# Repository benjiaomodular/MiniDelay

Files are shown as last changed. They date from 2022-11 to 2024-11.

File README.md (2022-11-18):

# MiniDelay

A three-knob delay module based on Rene Schmitz' PT2399 delay design. It’s a simple setup with input and output sections designed to work with Eurorack modular synthesizer levels (10Vpp).

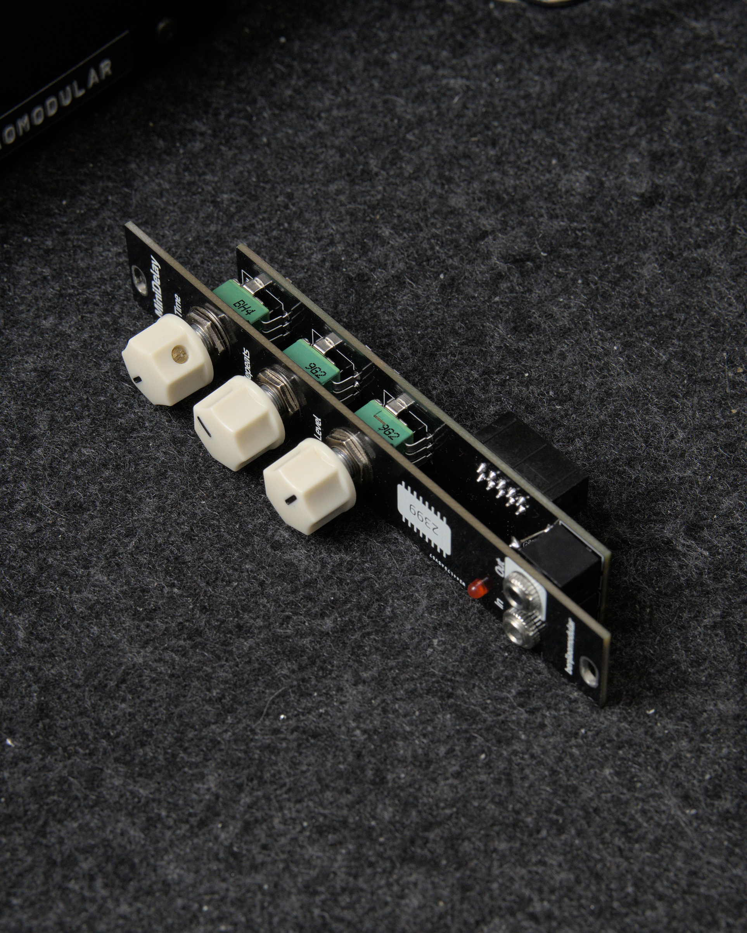
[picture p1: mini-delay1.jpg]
MiniDelay


# More info
For more information about this project, check out my website: https://benjiaomodular.com/post/2022-09-11-mini-delay/

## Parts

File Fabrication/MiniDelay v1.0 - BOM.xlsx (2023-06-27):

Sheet: MiniDelay
Part No. | Reference | Quantity | Value | Manufacturers Name | Manufacturers Part Number | Mfg # | Part Description | Type | LCSC Part # | Package
1 | AudioIn1 AudioOut1 | 2 | AudioJack2_SwitchT | Tayda Electronics | PJ-3001F | PJ-3001F | PJ-3001F 3.5mm Mono Phone Jack | Thru-hole | - | -
2 | C1 C2 | 2 | 22uF | Murata Electronics | GRM21BR61E226ME44L | GRM21BR61E226ME44L | Multilayer Ceramic Capacitors MLCC - SMD/SMT 22UF 25V 20% 0805 | Surface mount | C49678 | 805
3 | C10 C12 C15 C19 | 4 | 2.2nF | YAGEO | CC0603JRNPO9BN222 | CC0603JRNPO9BN222 | Multilayer Ceramic Capacitors MLCC - SMD/SMT 50V 2200pF C0G 0603 5% | Surface mount | C107043 | 603
4 | C14 | 1 | 330nF | YAGEO | CC0603KRX7R8BB334 | CC0603KRX7R8BB334 | Multilayer Ceramic Capacitors MLCC - SMD/SMT 25V 0.33uF X7R 0603 10% | Surface mount | C107070 | 603
5 | C16 | 1 | 15nF | YAGEO | AC0603KRX7R0BB153 | AC0603KRX7R0BB153 | Multilayer Ceramic Capacitors MLCC - SMD/SMT 100 V 0.015 uF X7R 0603 10% AEC-Q200 | Surface mount | C2210963 | 603
6 | C20 | 1 | 4.7nF | YAGEO | CC0603JRX7R9BB472 | CC0603JRX7R9BB472 | Multilayer Ceramic Capacitors MLCC - SMD/SMT 50V 4700pF X7R 0603 5% | Surface mount | C115060 | 603
7 | C21 | 1 | 10nF | YAGEO | CC0603JRX7R9BB103 | CC0603JRX7R9BB103 | Multilayer Ceramic Capacitors MLCC - SMD/SMT 50V 0.01uF X7R 0603 5% | Surface mount | C115056 | 603
8 | C22 | 1 | 68pF | YAGEO | CC0603GRNPO9BN680 | CC0603GRNPO9BN680 | Multilayer Ceramic Capacitors MLCC - SMD/SMT 50 V 68 pF C0G 0603 2% | Surface mount | C519457 | 603
9 | C3 C4 C8 C9 C11 C13 C17 | 7 | 100nF | YAGEO | CC0603JRX7R9BB104 | CC0603JRX7R9BB104 | Multilayer Ceramic Capacitors MLCC - SMD/SMT 50 V 0.1uF X7R 0603 5% | Surface mount | C91183 | 603
10 | C5 | 1 | 220nF | Murata Electronics | GCM188R71H224KA64D | GCM188R71H224KA64D | Multilayer Ceramic Capacitors MLCC - SMD/SMT .22UF 50V 10% 0603 | Surface mount | C97857 | 603
11 | C6 | 1 | 47pF | YAGEO | CC0603JRNPO9BN470 | CC0603JRNPO9BN470 | Multilayer Ceramic Capacitors MLCC - SMD/SMT 50 V 47 pF C0G 0603 5% | Surface mount | C105622 | 603
12 | C7 C18 | 2 | 1uF | Taiyo Yuden | UMK107AB7105KA-T | UMK107AB7105KA-T | Multilayer Ceramic Capacitors MLCC - SMD/SMT 0603 50VDC 1uF 10% X7R | Surface mount | C105174 | 603
13 | D1 | 1 | 3mm_LED | EKINGLUX | EL304RD | EL304RD | 3.0mm Round Through Hole LED | Thru-hole | C2856645 | -
14 | J1 | 1 | IDC_2x05 | XKB Connectivity | X9555WV-2X05-6TV01 | X9555WV-2X05-6TV01 | IDC Connector 2x05 2.54mm Pitch Straight | Thru-hole | C706914 | -
15 | LEVEL1 REPEATS1 | 2 | B10k | Alpha (Taiwan) | RD901F-40-15R1-B10K | RD901F-40-15R1-B10K | 10K OHM Linear Taper Potentiometer Round Shaft PCB 9mm | Thru-hole | - | RD901F
16 | R1 R16 | 2 | 1M | YAGEO | RC0603FR-071ML | RC0603FR-071ML | Thick Film Resistors - SMD 1 MOhms 100mW 0603 1% | Surface mount | C105578 | 603
17 | R18 | 1 | 68k | YAGEO | RC0603FR-0768KL | RC0603FR-0768KL | Thick Film Resistors - SMD 68 kOhms 100mW 0603 1% | Surface mount | C114633 | 603
18 | R2 R4 R8 R10 R11 R12 R13 R14 R15 | 9 | 10k | YAGEO | AC0603FR-0710KL | AC0603FR-0710KL | Thick Film Resistors - SMD 10 kOhms 100mW 0603 1% AEC-Q200 | Surface mount | C116677 | 603
19 | R3 R6 R17 R20 R21 | 5 | 100k | YAGEO | RC0603FR-07100KL | RC0603FR-07100KL | Thick Film Resistors - SMD 100 kOhms 100mW 0603 1% | Surface mount | C14675 | 603
20 | R5 | 1 | 2.7k | YAGEO | RC0603FR-072K7L | RC0603FR-072K7L | Thick Film Resistors - SMD 2.7 kOhms 100mW 0603 1% | Surface mount | C114612 | 603
21 | R7 R19 | 2 | 20k | YAGEO | RC0603FR-0720KL | RC0603FR-0720KL | Thick Film Resistors - SMD 20 kOhms 100mW 0603 1% | Surface mount | C105575 | 603
22 | R9 | 1 | 1k | YAGEO | RC0603FR-071KL | RC0603FR-071KL | Thick Film Resistors - SMD 1 kOhms 100mW 0603 1% | Surface mount | C22548 | 603
23 | TIME1 | 1 | B100k | Alpha (Taiwan) | RD901F-40-15R1-B100K | RD901F-40-15R1-B100K | 100K OHM Linear Taper Potentiometer Round Shaft PCB 9mm | Thru-hole | - | RD901F
24 | U1 | 1 | TL074 | STMicroelectronics | TL074IDT | TL074IDT | Operational Amplifiers - Op Amps Quad Low Noise JFET | Surface mount | C107644 | SOIC-14_150mil
25 | U2 | 1 | PT2399 | PTC(Princeton Tech) | PT2399-SN | PT2399-SN | SOP-16_150mil Audio Interface ICs ROHS | Surface mount | C126407 | SOP-16_150mil
26 | U3 | 1 | L7805 | STMicroelectronics | L7805CDT-TR | L7805CDT-TR | 62dB@(120Hz) 1.5A 2V@(1A) Fixed 5V~5V Positive 1 35V TO-252-3 Linear Voltage Regulators (LDO) ROHS | Surface mount | C310413 | TO-252-3
 |  | 53

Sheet: Sheet2
Part No. | Reference | Quantity | Value | Manufacturers Name | Manufacturers Part Number | Mfg # | Part Description | Type | LCSC Part # | Package
2 | C1 C2 | 2 | 22uF | YAGEO | CC0805KRX7R9BB104 | CC0805KRX7R9BB104 | Multilayer Ceramic Capacitors MLCC - SMD/SMT 50 V 0.1uF X7R 0805 10% | Surface mount | C49678 | 805
3 | C10 C12 C15 C19 | 4 | 2.2nF | YAGEO | CC0603JRNPO9BN222 | CC0603JRNPO9BN222 | Multilayer Ceramic Capacitors MLCC - SMD/SMT 50V 2200pF C0G 0603 5% | Surface mount | C107043 | 603
4 | C14 | 1 | 330nF | YAGEO | CC0603KRX7R8BB334 | CC0603KRX7R8BB334 | Multilayer Ceramic Capacitors MLCC - SMD/SMT 25V 0.33uF X7R 0603 10% | Surface mount | C107070 | 603
5 | C16 | 1 | 15nF | YAGEO | AC0603KRX7R0BB153 | AC0603KRX7R0BB153 | Multilayer Ceramic Capacitors MLCC - SMD/SMT 100 V 0.015 uF X7R 0603 10% AEC-Q200 | Surface mount | C2210963 | 603
6 | C20 | 1 | 4.7nF | YAGEO | CC0603JRX7R9BB472 | CC0603JRX7R9BB472 | Multilayer Ceramic Capacitors MLCC - SMD/SMT 50V 4700pF X7R 0603 5% | Surface mount | C115060 | 603
7 | C21 | 1 | 10nF | YAGEO | CC0603JRX7R9BB103 | CC0603JRX7R9BB103 | Multilayer Ceramic Capacitors MLCC - SMD/SMT 50V 0.01uF X7R 0603 5% | Surface mount | C115056 | 603
8 | C22 | 1 | 68pF | YAGEO | CC0603GRNPO9BN680 | CC0603GRNPO9BN680 | Multilayer Ceramic Capacitors MLCC - SMD/SMT 50 V 68 pF C0G 0603 2% | Surface mount | C519457 | 603
9 | C3 C4 C8 C9 C11 C13 C17 | 7 | 100nF | YAGEO | CC0603JRX7R9BB104 | CC0603JRX7R9BB104 | Multilayer Ceramic Capacitors MLCC - SMD/SMT 50 V 0.1uF X7R 0603 5% | Surface mount | C91183 | 603
10 | C5 | 1 | 220nF | Murata Electronics | GCM188R71H224KA64D | GCM188R71H224KA64D | Multilayer Ceramic Capacitors MLCC - SMD/SMT .22UF 50V 10% 0603 | Surface mount | C97857 | 603
11 | C6 | 1 | 47pF | YAGEO | CC0603JRNPO9BN470 | CC0603JRNPO9BN470 | Multilayer Ceramic Capacitors MLCC - SMD/SMT 50 V 47 pF C0G 0603 5% | Surface mount | C105622 | 603
12 | C7 C18 | 2 | 1uF | Taiyo Yuden | UMK107AB7105KA-T | UMK107AB7105KA-T | Multilayer Ceramic Capacitors MLCC - SMD/SMT 0603 50VDC 1uF 10% X7R | Surface mount | C105174 | 603
16 | R1 R16 | 2 | 1M | YAGEO | RC0603FR-071ML | RC0603FR-071ML | Thick Film Resistors - SMD 1 MOhms 100mW 0603 1% | Surface mount | C105578 | 603
17 | R18 | 1 | 68k | YAGEO | RC0603FR-0768KL | RC0603FR-0768KL | Thick Film Resistors - SMD 68 kOhms 100mW 0603 1% | Surface mount | C114633 | 603
18 | R2 R4 R8 R10 R11 R12 R13 R14 R15 | 9 | 10k | YAGEO | AC0603FR-0710KL | AC0603FR-0710KL | Thick Film Resistors - SMD 10 kOhms 100mW 0603 1% AEC-Q200 | Surface mount | C116677 | 603
19 | R3 R6 R17 R20 R21 | 5 | 100k | YAGEO | RC0603FR-07100KL | RC0603FR-07100KL | Thick Film Resistors - SMD 100 kOhms 100mW 0603 1% | Surface mount | C14675 | 603
20 | R5 | 1 | 2.7k | YAGEO | RC0603FR-072K7L | RC0603FR-072K7L | Thick Film Resistors - SMD 2.7 kOhms 100mW 0603 1% | Surface mount | C114612 | 603
21 | R7 R19 | 2 | 20k | YAGEO | RC0603FR-0720KL | RC0603FR-0720KL | Thick Film Resistors - SMD 20 kOhms 100mW 0603 1% | Surface mount | C105575 | 603
22 | R9 | 1 | 1k | YAGEO | RC0603FR-071KL | RC0603FR-071KL | Thick Film Resistors - SMD 1 kOhms 100mW 0603 1% | Surface mount | C22548 | 603
24 | U1 | 1 | TL074 | STMicroelectronics | TL074IDT | TL074IDT | Operational Amplifiers - Op Amps Quad Low Noise JFET | Surface mount | C107644 | SOIC-14_150mil
25 | U2 | 1 | PT2399 | PTC(Princeton Tech) | PT2399-SN | PT2399-SN | SOP-16_150mil Audio Interface ICs ROHS | Surface mount | C126407 | SOP-16_150mil
26 | U3 | 1 | L7805 | STMicroelectronics | L7805CDT-TR | L7805CDT-TR | 62dB@(120Hz) 1.5A 2V@(1A) Fixed 5V~5V Positive 1 35V TO-252-3 Linear Voltage Regulators (LDO) ROHS | Surface mount | C310413 | TO-252-3
 |  | 46

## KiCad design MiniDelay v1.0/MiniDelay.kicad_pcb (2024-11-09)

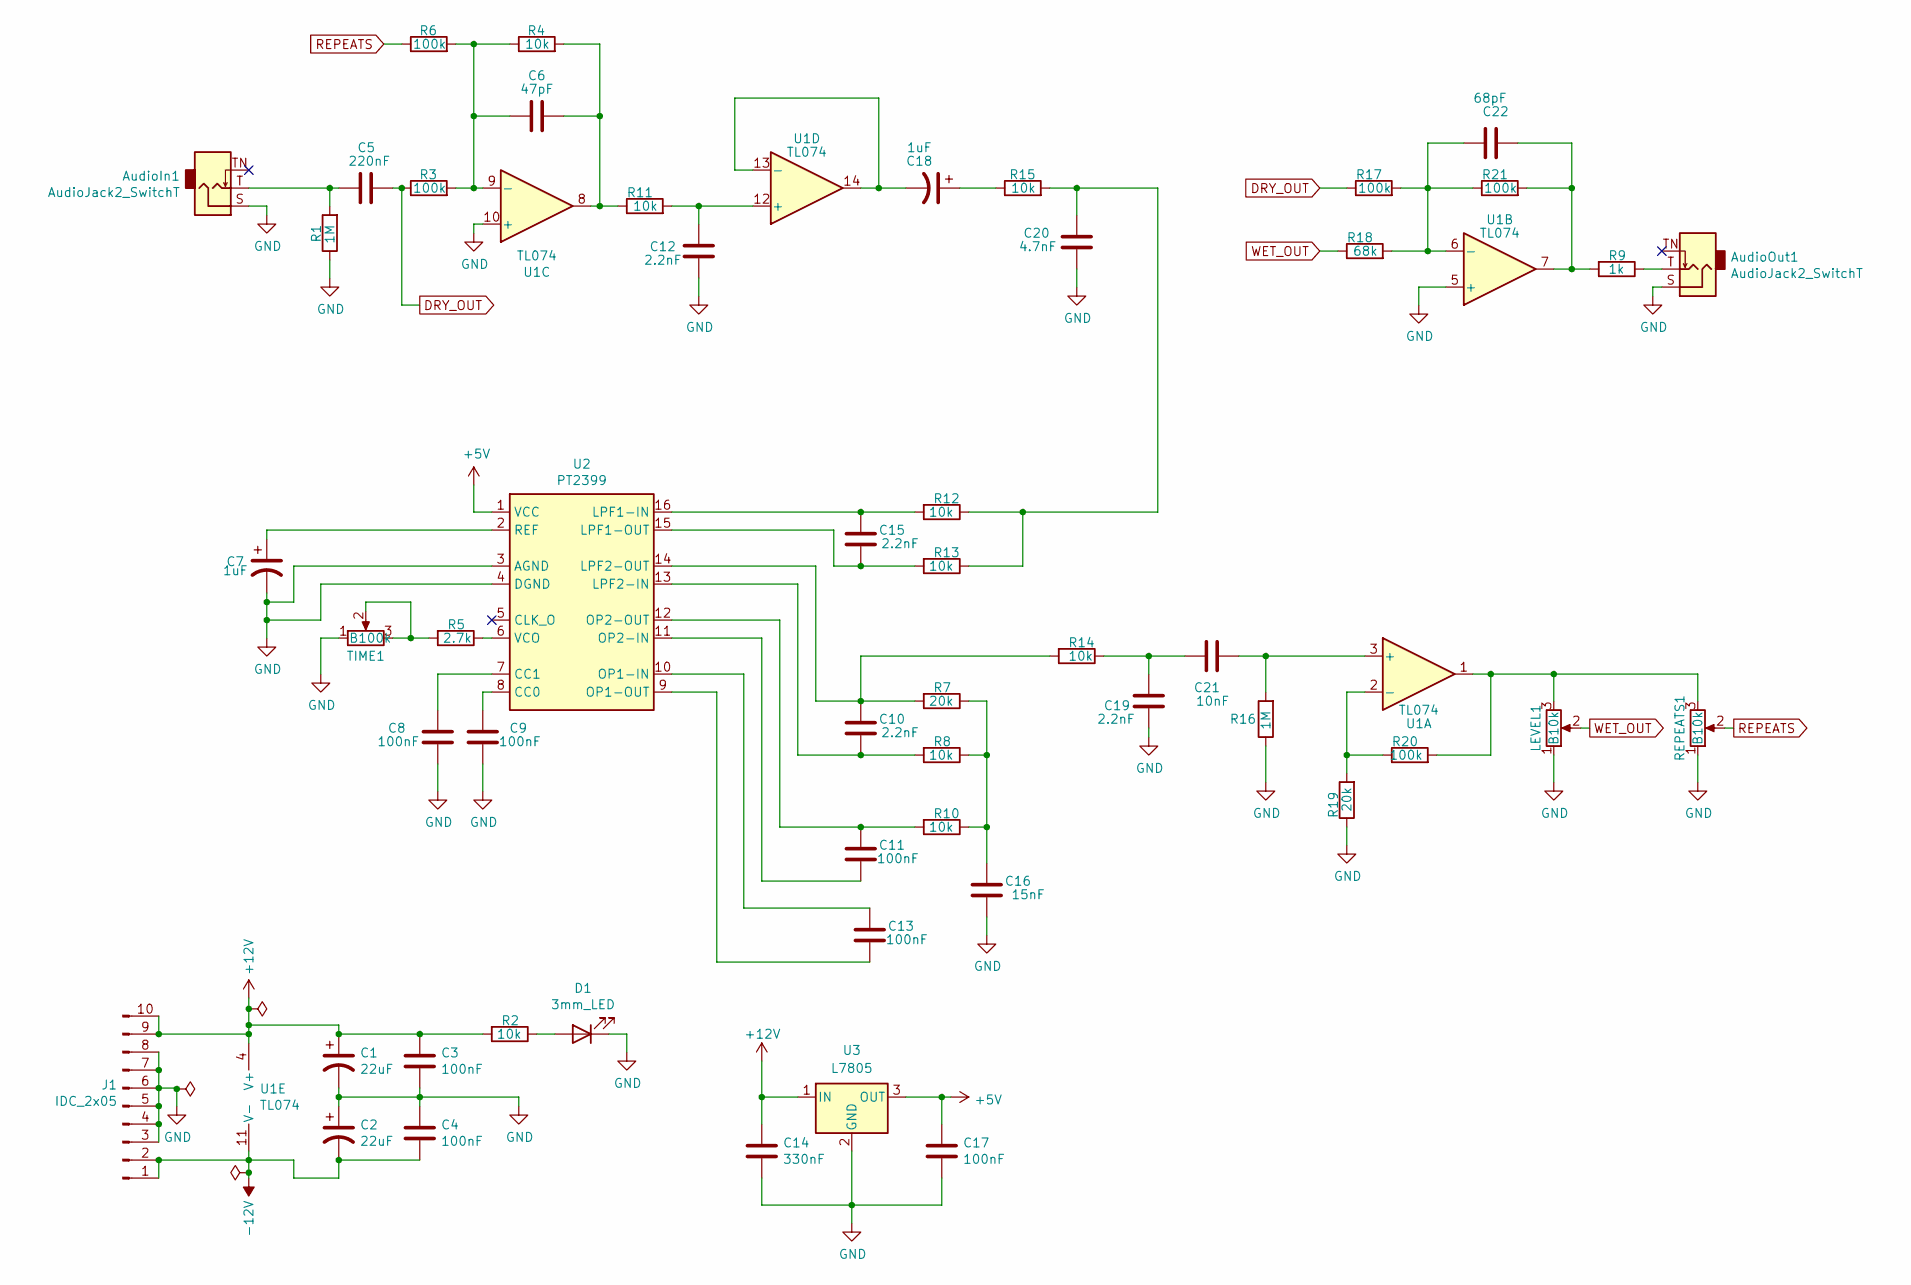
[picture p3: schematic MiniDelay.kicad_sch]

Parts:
AudioIn1: AudioJack2_SwitchT; AudioJack_3.5mm; Manufacturers Part Numb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 PJ-3001F
AudioOut1: AudioJack2_SwitchT; AudioJack_3.5mm; Manufacturers Part Numb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 PJ-3001F
C1, C2: 22uF; C_0805_2012Metric_Pad1.18x1.45mm_HandSolder; Mfg # CC0805KRX7R9BB104; LCSC Part # C49678
C3, C4, C8, C9, C11, C13, C17: 100nF; C_0603_1608Metric_Pad1.08x0.95mm_HandSolder; Mfg # CC0603JRX7R9BB104; LCSC Part # C91183
C5: 220nF; C_0603_1608Metric_Pad1.08x0.95mm_HandSolder; Mfg # GCM188R71H224KA64D; LCSC Part # C97857
C6: 47pF; C_0603_1608Metric_Pad1.08x0.95mm_HandSolder; Mfg # CC0603JRNPO9BN470; LCSC Part # C105622
C7, C18: 1uF; C_0603_1608Metric_Pad1.08x0.95mm_HandSolder; Mfg # UMK107AB7105KA-T; LCSC Part # C105174
C10, C12, C15, C19: 2.2nF; C_0603_1608Metric_Pad1.08x0.95mm_HandSolder; Mfg # CC0603JRNPO9BN222; LCSC Part # C107043
C14: 330nF; C_0603_1608Metric_Pad1.08x0.95mm_HandSolder; Mfg # CC0603KRX7R8BB334; LCSC Part # C107070
C16: 15nF; C_0603_1608Metric_Pad1.08x0.95mm_HandSolder; Mfg # AC0603KRX7R0BB153; LCSC Part # C2210963
C20: 4.7nF; C_0603_1608Metric_Pad1.08x0.95mm_HandSolder; Mfg # CC0603JRX7R9BB472; LCSC Part # C115060
C21: 10nF; C_0603_1608Metric_Pad1.08x0.95mm_HandSolder; Mfg # CC0603JRX7R9BB103; LCSC Part # C115056
C22: 68pF; C_0603_1608Metric_Pad1.08x0.95mm_HandSolder; Mfg # CC0603GRNPO9BN680; LCSC Part # C519457
D1: 3mm_LED; LED_D3.0mm; Manufacturers Part Numb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 EL304RD; LCSC Part # C2856645
J1: IDC_2x05; IDC-Header_2x05_P2.54mm_Vertical; Manufacturers Part Numb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 X9555WV-2X05-6TV01; LCSC Part # C706914
LEVEL1: B10k; Potentiometer_RV09; Manufacturers Part Numb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 RD901F-40-15R1-B10K
R1, R16: 1M; R_0603_1608Metric_Pad0.98x0.95mm_HandSolder; Mfg # RC0603FR-071ML; LCSC Part # C105578
R2, R4, R8, R10, R11, R12, R13, R14, R15: 10k; R_0603_1608Metric_Pad0.98x0.95mm_HandSolder; Mfg # AC0603FR-0710KL; LCSC Part # C116677
R3, R6, R17, R20, R21: 100k; R_0603_1608Metric_Pad0.98x0.95mm_HandSolder; Mfg # RC0603FR-07100KL; LCSC Part # C14675
R5: 2.7k; R_0603_1608Metric_Pad0.98x0.95mm_HandSolder; Mfg # RC0603FR-072K7L; LCSC Part # C114612
R7, R19: 20k; R_0603_1608Metric_Pad0.98x0.95mm_HandSolder; Mfg # RC0603FR-0720KL; LCSC Part # C105575
R9: 1k; R_0603_1608Metric_Pad0.98x0.95mm_HandSolder; Mfg # RC0603FR-071KL; LCSC Part # C22548
R18: 68k; R_0603_1608Metric_Pad0.98x0.95mm_HandSolder; Mfg # RC0603FR-0768KL; LCSC Part # C114633
REPEATS1: B10k; Potentiometer_RV09; Manufacturers Part Numb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 RD901F-40-15R1-B10K
TIME1: B100k; Potentiometer_RV09; Manufacturers Part Numb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 RD901F-40-15R1-B100K
U1: TL074; SOIC-14_3.9x8.7mm_P1.27mm; Mfg # TL074IDT; LCSC Part # C107644
U2: PT2399; SOP-16_4.55x10.3mm_P1.27mm; Mfg # PT2399-SN; LCSC Part # C126407
U3: L7805; TO-252-2; Mfg # L7805CDT-TR; LCSC Part # C310413

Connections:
+5V: C17.1, U2.1 (VCC), U3.3 (OUT)
+12V: C1.1, C3.1, C14.1, J1.9, J1.10, R2.2, U1.4 (V+), U3.1 (IN)
-12V: C2.2, C4.2, J1.1, J1.2, U1.11 (V-)
DRY_OUT: C5.1, R3.1, R17.1
GND: AudioIn1.S, AudioOut1.S, C1.2, C2.1, C3.2, C4.1, C7.2, C8.1, C9.1, C12.1, C14.2, C16.1, C17.2, C19.1, C20.2, D1.1 (K), J1.3, J1.4, J1.5, J1.6, J1.7, J1.8, LEVEL1.1, R1.1, R16.1, R19.1, REPEATS1.1, TIME1.1, U1.5 (+), U1.10 (+), U2.3 (AGND), U2.4 (DGND), U3.2 (GND)
unnamed: AudioIn1.T, C5.2, R1.2
unnamed: AudioOut1.T, R9.1
unnamed: C6.1, R4.2, R11.1, U1.8
unnamed: C6.2, R3.2, R4.1, R6.2, U1.9 (-)
unnamed: C7.1, U2.2 (REF)
unnamed: C8.2, U2.7 (CC1)
unnamed: C9.2, U2.8 (CC0)
unnamed: C10.1, R8.2, U2.13 (LPF2-IN)
unnamed: C10.2, R7.2, R14.2, U2.14 (LPF2-OUT)
unnamed: C11.1, U2.11 (OP2-IN)
unnamed: C11.2, R10.2, U2.12 (OP2-OUT)
unnamed: C12.2, R11.2, U1.12 (+)
unnamed: C13.1, U2.9 (OP1-OUT)
unnamed: C13.2, U2.10 (OP1-IN)
unnamed: C15.1, R13.2, U2.15 (LPF1-OUT)
unnamed: C15.2, R12.2, U2.16 (LPF1-IN)
unnamed: C16.2, R7.1, R8.1, R10.1
unnamed: C18.1, R15.1
unnamed: C18.2, U1.13 (-), U1.14
unnamed: C19.2, C21.1, R14.1
unnamed: C20.1, R12.1, R13.1, R15.2
unnamed: C21.2, R16.2, U1.3 (+)
unnamed: C22.1, R9.2, R21.2, U1.7
unnamed: C22.2, R17.2, R18.2, R21.1, U1.6 (-)
unnamed: D1.2 (A), R2.1
unnamed: LEVEL1.3, R20.2, REPEATS1.3, U1.1
unnamed: R5.1, U2.6 (VCO)
unnamed: R5.2, TIME1.2, TIME1.3
unnamed: R19.2, R20.1, U1.2 (-)
REPEATS: R6.1, REPEATS1.2
WET_OUT: LEVEL1.2, R18.1

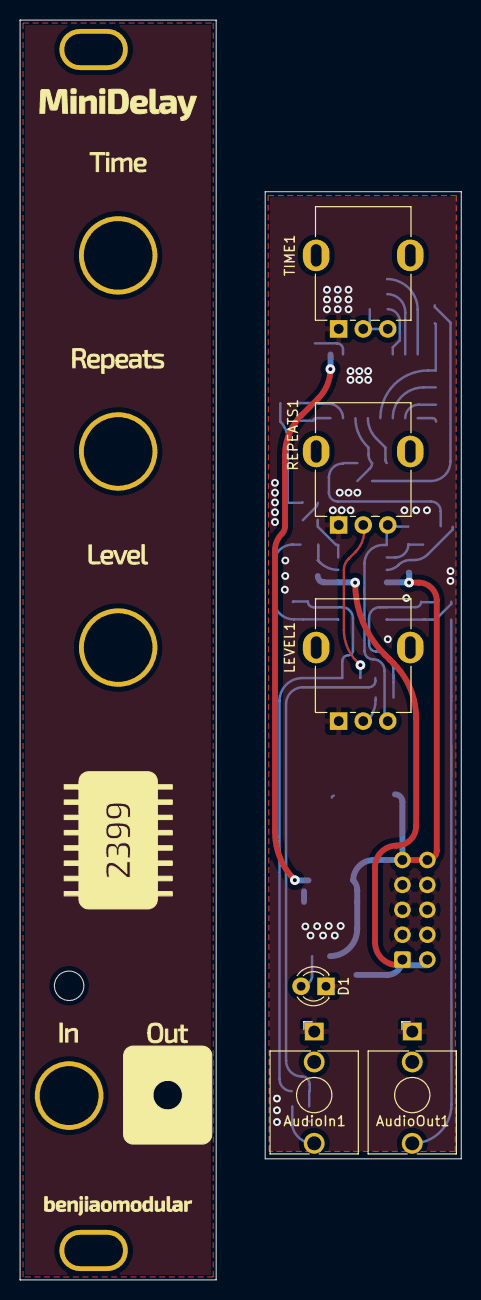
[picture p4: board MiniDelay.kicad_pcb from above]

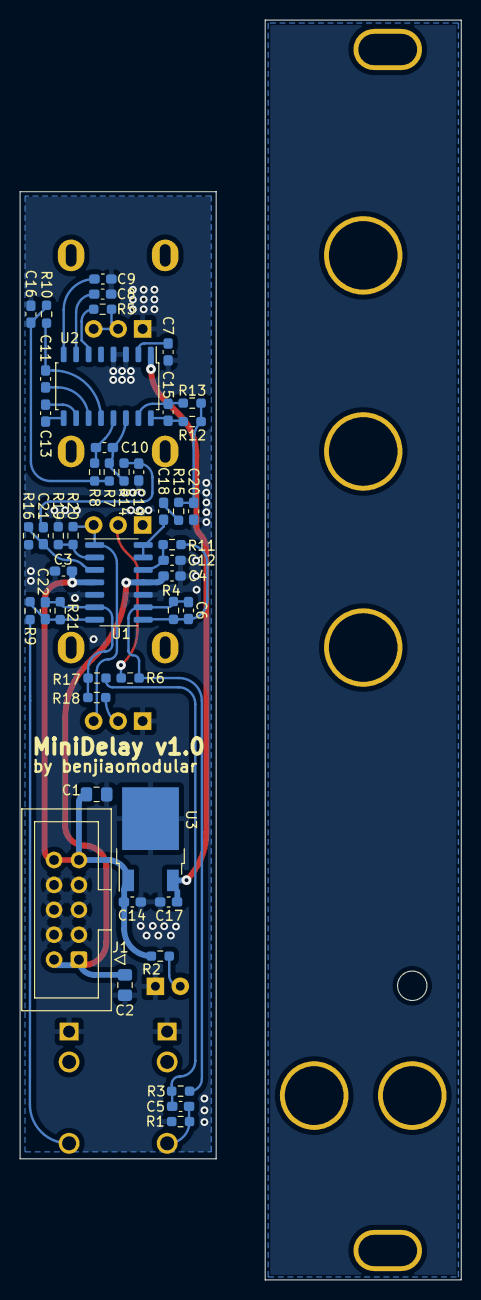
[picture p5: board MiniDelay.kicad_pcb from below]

Board: 2 copper layers, 20.0 x 98.7 mm, 53 parts (47 on the bottom side), 36 nets.

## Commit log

2022-10-11 Hello git
    [MiniDelay.kicad_pcb, MiniDelay.kicad_sch, power.kicad_sch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]
2022-10-24 Moved everything to SMD
    [MiniDelay.kicad_pcb, MiniDelay.kicad_sch]
2022-10-24 Updated bom using LCSC
    [MiniDelay-B_Cu.gbr, MiniDelay-B_Mask.gbr, MiniDelay-B_Paste.gbr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]
2022-10-25 Worked on BOM
    [MiniDelay.kicad_pcb, MiniDelay.kicad_sch]
2022-10-25 Complete BOM
    [MiniDelay.kicad_sch]
2022-10-25 Added part descriptions
    [MiniDelay.kicad_sch]
2022-11-14 Final v1.0 PCB
    [MiniDelay v1.0 - BOM.xlsx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]
2022-11-15 Refactored BOM
    [MiniDelay v1.0 - BOM.csv, MiniDelay v1.0 - BOM.xlsx, MiniDelay v1.0 BOM.csv]
2022-11-15 More cleanup
    [power.kicad_sch, sockets.kicad_sch]
2022-11-18 Removed outdated bom
    [MiniDelay v1.0 - BOM.csv]
2023-06-27 Minor updates to kicad files
    [MiniDelay v1.0 - BOM.xlsx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]
2024-11-09 Cleaned up fabrication files
    [MiniDelay v1.0 - Front-B_Cu.gbr, MiniDelay v1.0 - Front-B_Mask.gbr, MiniDelay v1.0 - Front-B_Paste.gbr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]
